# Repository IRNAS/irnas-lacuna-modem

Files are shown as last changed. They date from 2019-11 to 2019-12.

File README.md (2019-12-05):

# Irnas Lacuna modem
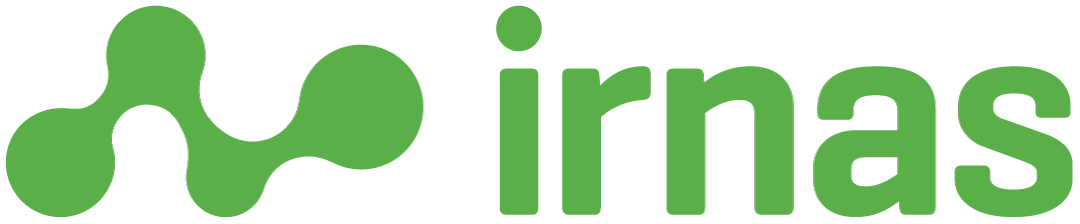
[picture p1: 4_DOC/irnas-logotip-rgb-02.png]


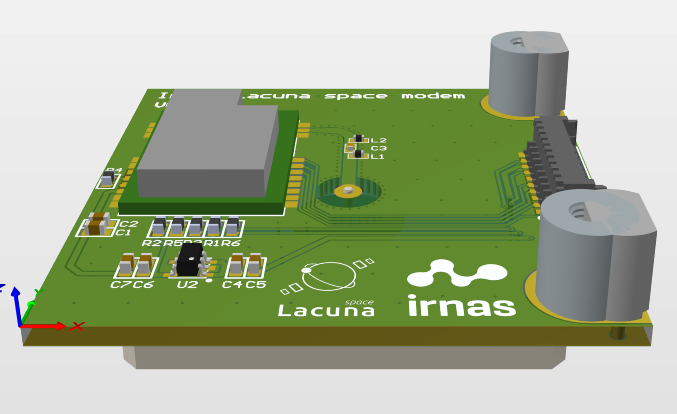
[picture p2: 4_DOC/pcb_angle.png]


## Folder structure
 - folder 1_SCHEMATIC includes Altium schematic files and PDF schematic
 - folder 2_PCB includes Altium PCB file, PDF PCB print and PDF 3D PCB print
 - folder 3_OUTPUT_FILES includes Gerber and NC Drill files, PDF Assembly file and Bill of Material
 - folder 4_DOC includes 3D step model of PCB and photos of device
 - folder 5_ALTIUM_FILES incudes all Altium Designer files (Libraries, Output job, Project document, ...)

## Specification
Device consists of:
 - Top side:
   - LoRa module - E22-900M22S
   - Fixed LDO Voltage Regulator 3.3 V - MIC5504-3.3YM5-TR
   - 10 pin PicoBlade connector
 - Bottom side:
   - Patch antenna 868 MHz - ISMP.868.35.6.A.02

Dimensions:  
 - Lenght: 45 mm
 - Height: 45 mm
 - PCB thickness: 1.6 mm

Mounting pins:  
 - Vertical pin (https://www.we-online.com/catalog/en/WP-SMBU_BLIND-HOLE/)
 - Angled pin (https://www.we-online.com/catalog/en/2ND_TAXONOMY$WP-SMRA_PINS/)

Connector:  
 Pin 1 - NC  
 Pin 2 - SPI_MOSI  
 Pin 3 - SPI_MISO  
 Pin 4 - SPI_SCK  
 Pin 5 - SPI_NSS  
 Pin 6 - NC  
 Pin 7 - DIO1  
 Pin 8 - 5V  
 Pin 9 - GPIO1  
 Pin 10 - GND  

## Features:
 - LoRa communication module with micro RF connector and patch antenna
 - Voltage regulator to 3.3 V

## License

All our projects are as usefully open-source as possible.

Hardware including documentation is licensed under [CERN OHL v.1.2. license](http://www.ohwr.org/licenses/cern-ohl/v1.2)

Firmware and software originating from the project is licensed under [GNU GENERAL PUBLIC LICENSE v3](http://www.gnu.org/licenses/gpl-3.0.en.html).

Open data generated by our projects is licensed under [CC0](https://creativecommons.org/publicdomain/zero/1.0/legalcode).

All our websites and additional documentation are licensed under [Creative Commons Attribution-ShareAlike 4 .0 Unported License](https://creativecommons.org/licenses/by-sa/4.0/legalcode).

What this means is that you can use hardware, firmware, software and documentation without paying a royalty and knowing that you'll be able to use your version forever. You are also free to make changes but if you share these changes then you have to do so on the same conditions that you enjoy.

Koruza, GoodEnoughCNC and IRNAS are all names and marks of Institut IRNAS Race. 
You may use these names and terms only to attribute the appropriate entity as required by the Open Licences referred to above. You may not use them in any other way and in particular you may not use them to imply endorsement or authorization of any hardware that you design, make or sell.

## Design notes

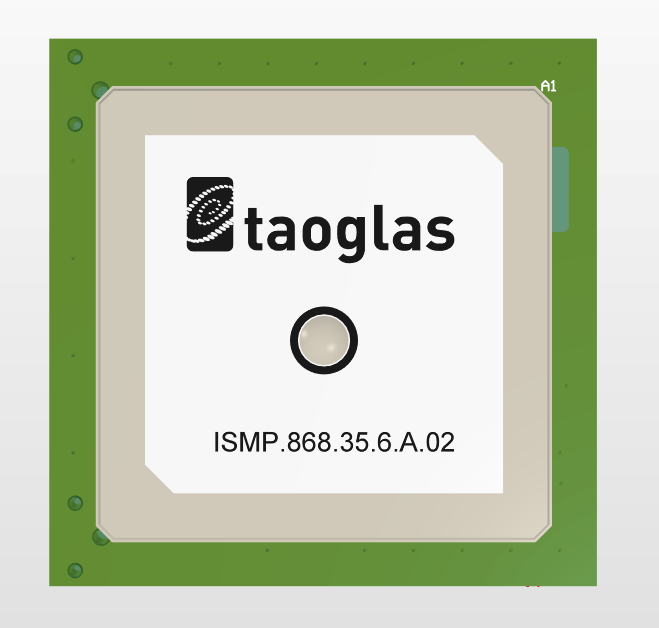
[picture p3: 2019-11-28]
4_DOC/pcb_bottom.png

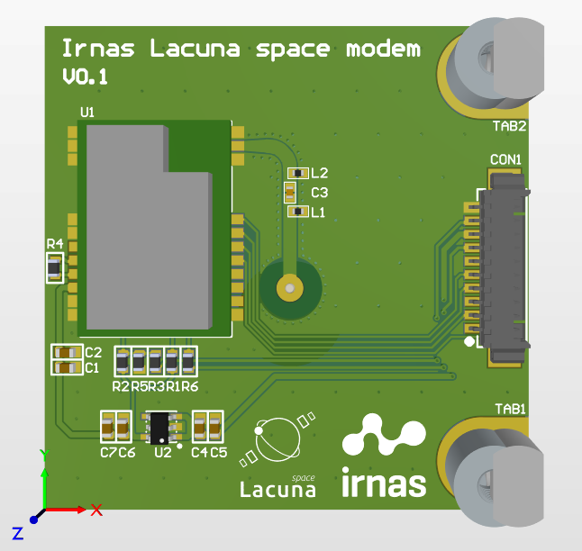
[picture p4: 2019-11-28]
4_DOC/pcb_top.png

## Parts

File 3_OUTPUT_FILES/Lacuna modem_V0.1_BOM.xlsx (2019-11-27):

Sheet: Part List Report
 | Component list |  |  | Lacuna modem
 | Source Data From: | Lacuna_modem.PrjPCB |  |  | Contact:
 | Project: | Lacuna_modem.PrjPCB
 | Variant: | None |  |  |  |  |  |  | IRNAS
 | Report Date: | 22. 11. 2019 | 10:42 |  |  |  |  |  | www.irnas.eu
 | Print Date: | 2019-11-22 | 10:42:34
# | Manufacturer Part Number | Manufacturer | Description | Footprint | Designator | Quantity | Supplier 1 | Supplier Part Number 1 | Supplier Order Qty 1 | Supplier Stock 1 | Supplier Unit Price 1 | Supplier Subtotal 1 | Supplier Currency 1
1 | C0402C189B5GACTU | KEMET | Multilayer Ceramic Capacitors MLCC - SMD/SMT 50volts 1.8pF C0G | CAP0402 | C3 | 1 | Farnell | 2820847
2 | GRM188R61H105KAALD | MURATA | MURATA - GRM188R61H105KAALD - CAP, MLCC, X5R, 1UF, 50V, 0603 | CAP0603 | C1, C4, C7 | 3 | Farnell | 1845736
3 | GRM188R71C104KA01J | MURATA | MURATA - GRM188R71C104KA01J - CAP, MLCC, X7R, 0.1UF, 16V, 0603 | CAP0603 | C2, C5, C6 | 3 | Farnell | 2688519
4 |  |  |  | E22-900M22S | U1 | 1
5 | LQG15HN4N3S02D | Murata | Inductor RF Chip Multi-Layer 4.3nH 0.3nH 100MHz 8Q-Factor Air 300mA 210mOhm DCR 0402 Paper T/R | IND0402 | L1, L2 | 2 | Digi-Key | 490-6563-1-ND
6 | SR42I010-R | Antenova | Patch Antenna, 868MHz, 2.17dBi Gain, 50ohm, Right Hand Circular Polarisation, Adhesive/Pin | ISMP.868.35.6.A.02 | A1 | 1 | Farnell | 2949079
7 |  |  | Wire-To-Board Connector, Right Angle, 1.25 mm, 10 Contacts, Header, PicoBlade 53261 Series | PICOBLADE 10PIN | CON1 | 1 | Farnell | 1125377
8 | CR0603-J/-000ELF | BOURNS | BOURNS - CR0603-J/-000ELF - RES, THICK FILM, 0R, 5%, 0.1W, 0603 | RES0603 | R3, R4, R6 | 3 | Farnell | 2008343
9 | MCMR06X103 JTL | MULTICOMP | MULTICOMP - MCMR06X103 JTL - RES, CERAMIC, 10K, 5%, 0.1W, 0603 | RES0603 | R1, R2, R5 | 3 | Farnell | 2073356
10 | LM2596DSADJG | ON SEMICONDUCTOR | Fixed LDO Voltage Regulator, 2.5V to 5.5V, 160mV Dropout, 3.3Vout, 300mAout, SOT-23-5 | SOT23-5 | U2 | 1 | Farnell | 2510377
11 |  |  | WP-SMBU SMD Internal blind-hole thread w. Pins | WP-SMBU | TAB1, TAB2 | 2 | Farnell | 2405986
 |  |  |  |  |  | 21 |  |  | 0 |  |  | 0
Approved |  |  |  | Notes
 |  |  |  | pcs: |  | 20 |  | Total |  | 0 |  | <none>
 |  |  |  |  |  |  |  | Price for 1pcs |  | 0.00 |  | <none>

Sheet: Project Information
Project Full Path | D:\OneDrive\IRNAS-Common\_NEW-IRNAS-COMMON\Lacuna-modem\Electronics\Lacuna_modem.PrjPCB
Project Filename | Lacuna_modem.PrjPCB
Variant Name | None
Data-Source Filename | Lacuna_modem.PrjPCB
Data-Source Full Path | D:\OneDrive\IRNAS-Common\_NEW-IRNAS-COMMON\Lacuna-modem\Electronics\Lacuna_modem.PrjPCB
Title | BOM for Project [Lacuna_modem.PrjPCB] (No PCB Document Selected)
Total Quantity | 21
Report Time | 10:42
Report Date | 22. 11. 2019
Report Date & Tine | 22. 11. 2019 10:42
Output Name | BOM
Output Type | BOM_PartType
Output Generator Name | BOM
Output Generator Description | Bill of Materials

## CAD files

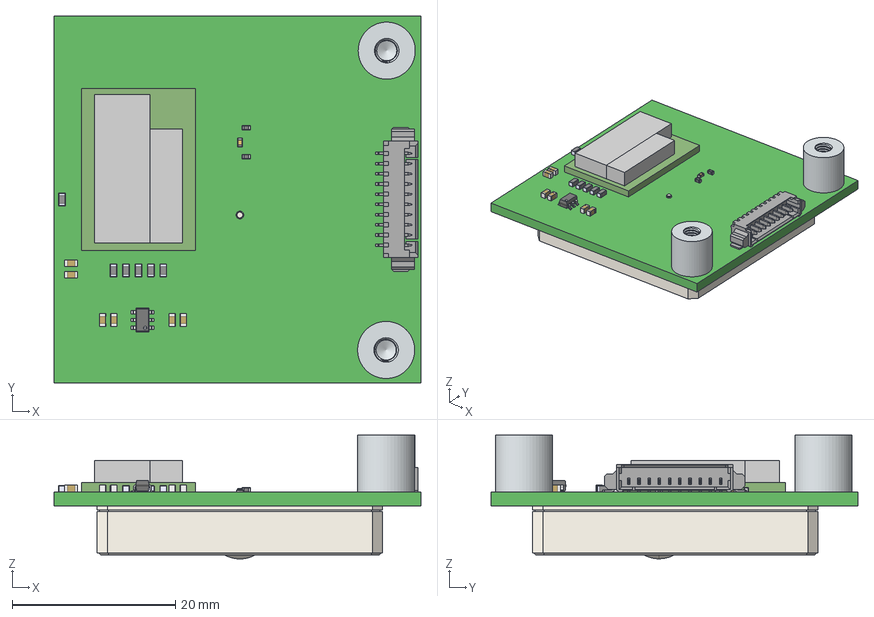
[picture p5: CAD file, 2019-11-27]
3_OUTPUT_FILES/Lacuna modem_V0.1_3D STEP.step
45.0 x 45.0 x 15.2 mm
7466103_(rev1) x 2
SOT23-6-2
Extruded x 3
R0603 x 6
Open_CASCADE_STEP_translator_6.8_1.1.1 x 2
Open_CASCADE_STEP_translator_6.8_1.1.2 x 2
Open_CASCADE_STEP_translator_6.8_1.2.1 x 2
Conn_Molex_53261-1071_eec_RGB6710886 x 56
C_SMD_0603 x 6
Open_CASCADE_STEP_translator_6.8_4.1.1
Open_CASCADE_STEP_translator_6.8_4.1.2
Open_CASCADE_STEP_translator_6.8_4.2.1
ISMP.868.35.6.A.02

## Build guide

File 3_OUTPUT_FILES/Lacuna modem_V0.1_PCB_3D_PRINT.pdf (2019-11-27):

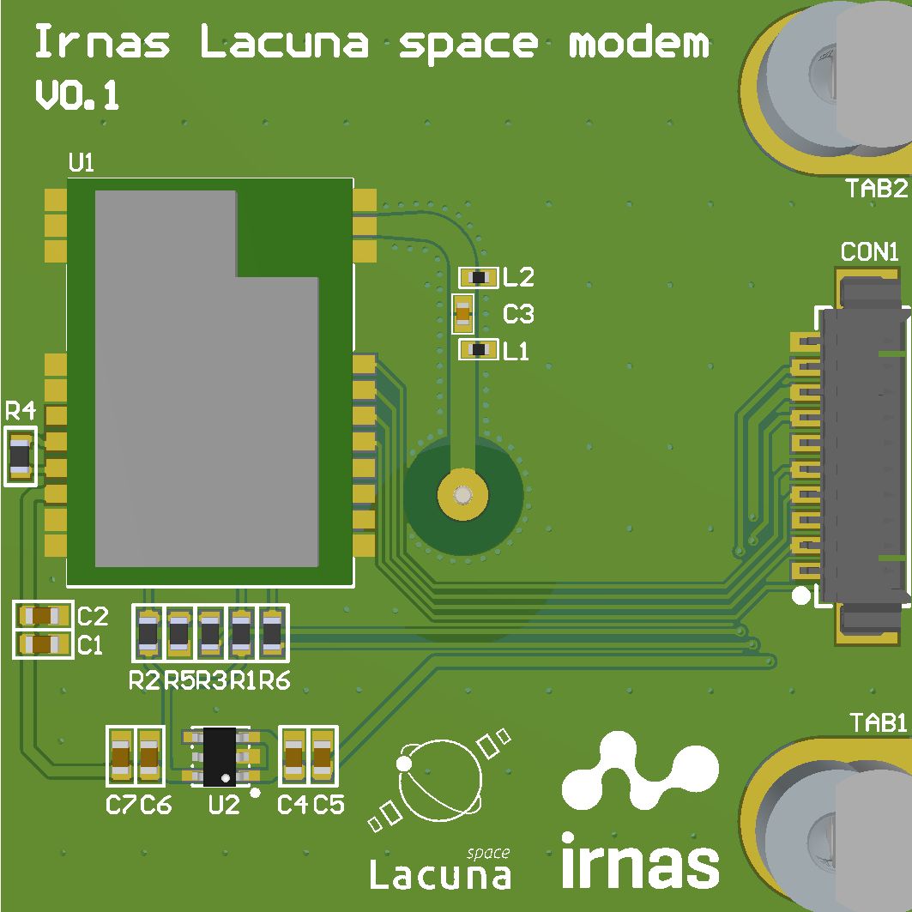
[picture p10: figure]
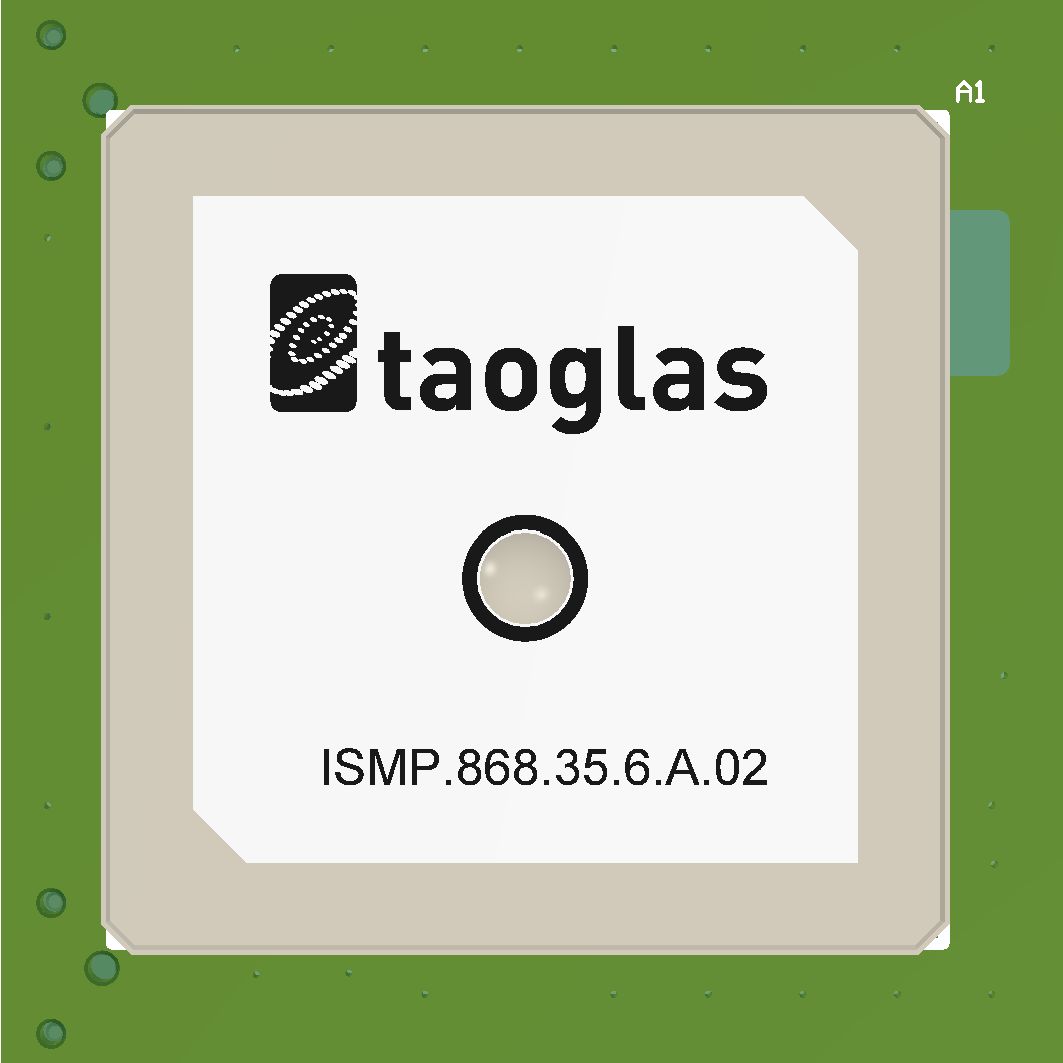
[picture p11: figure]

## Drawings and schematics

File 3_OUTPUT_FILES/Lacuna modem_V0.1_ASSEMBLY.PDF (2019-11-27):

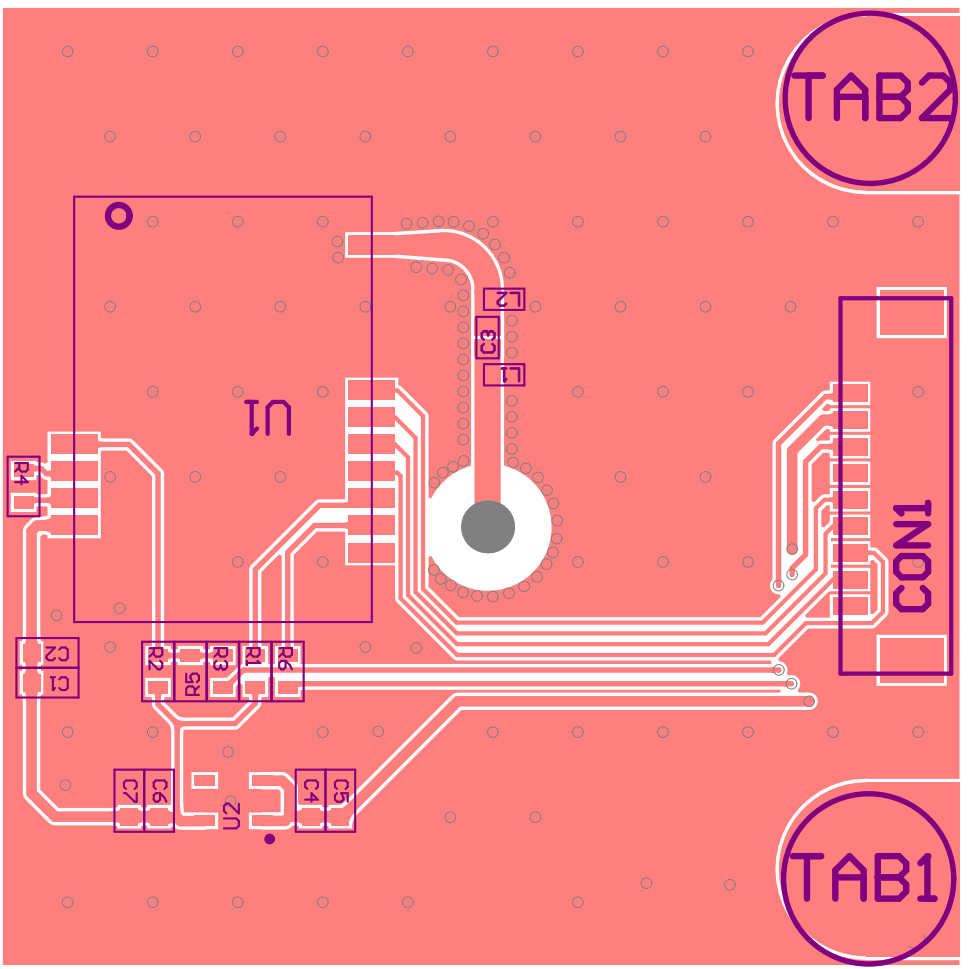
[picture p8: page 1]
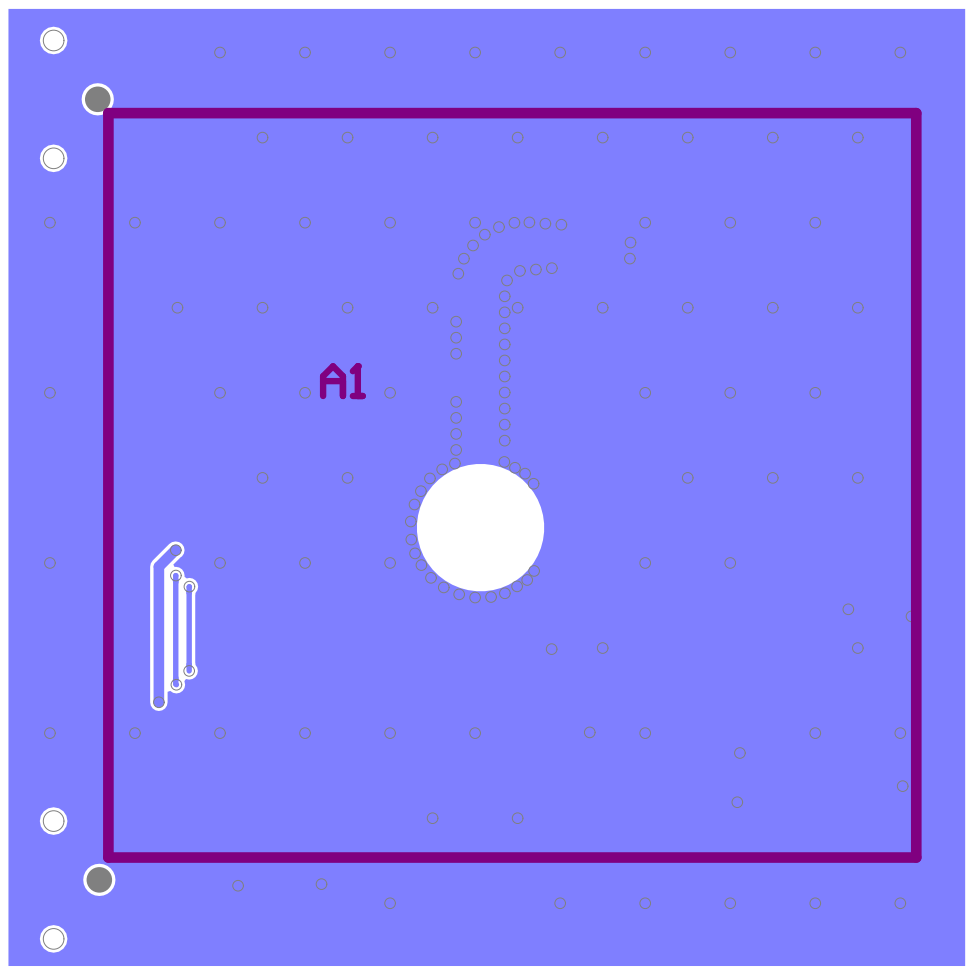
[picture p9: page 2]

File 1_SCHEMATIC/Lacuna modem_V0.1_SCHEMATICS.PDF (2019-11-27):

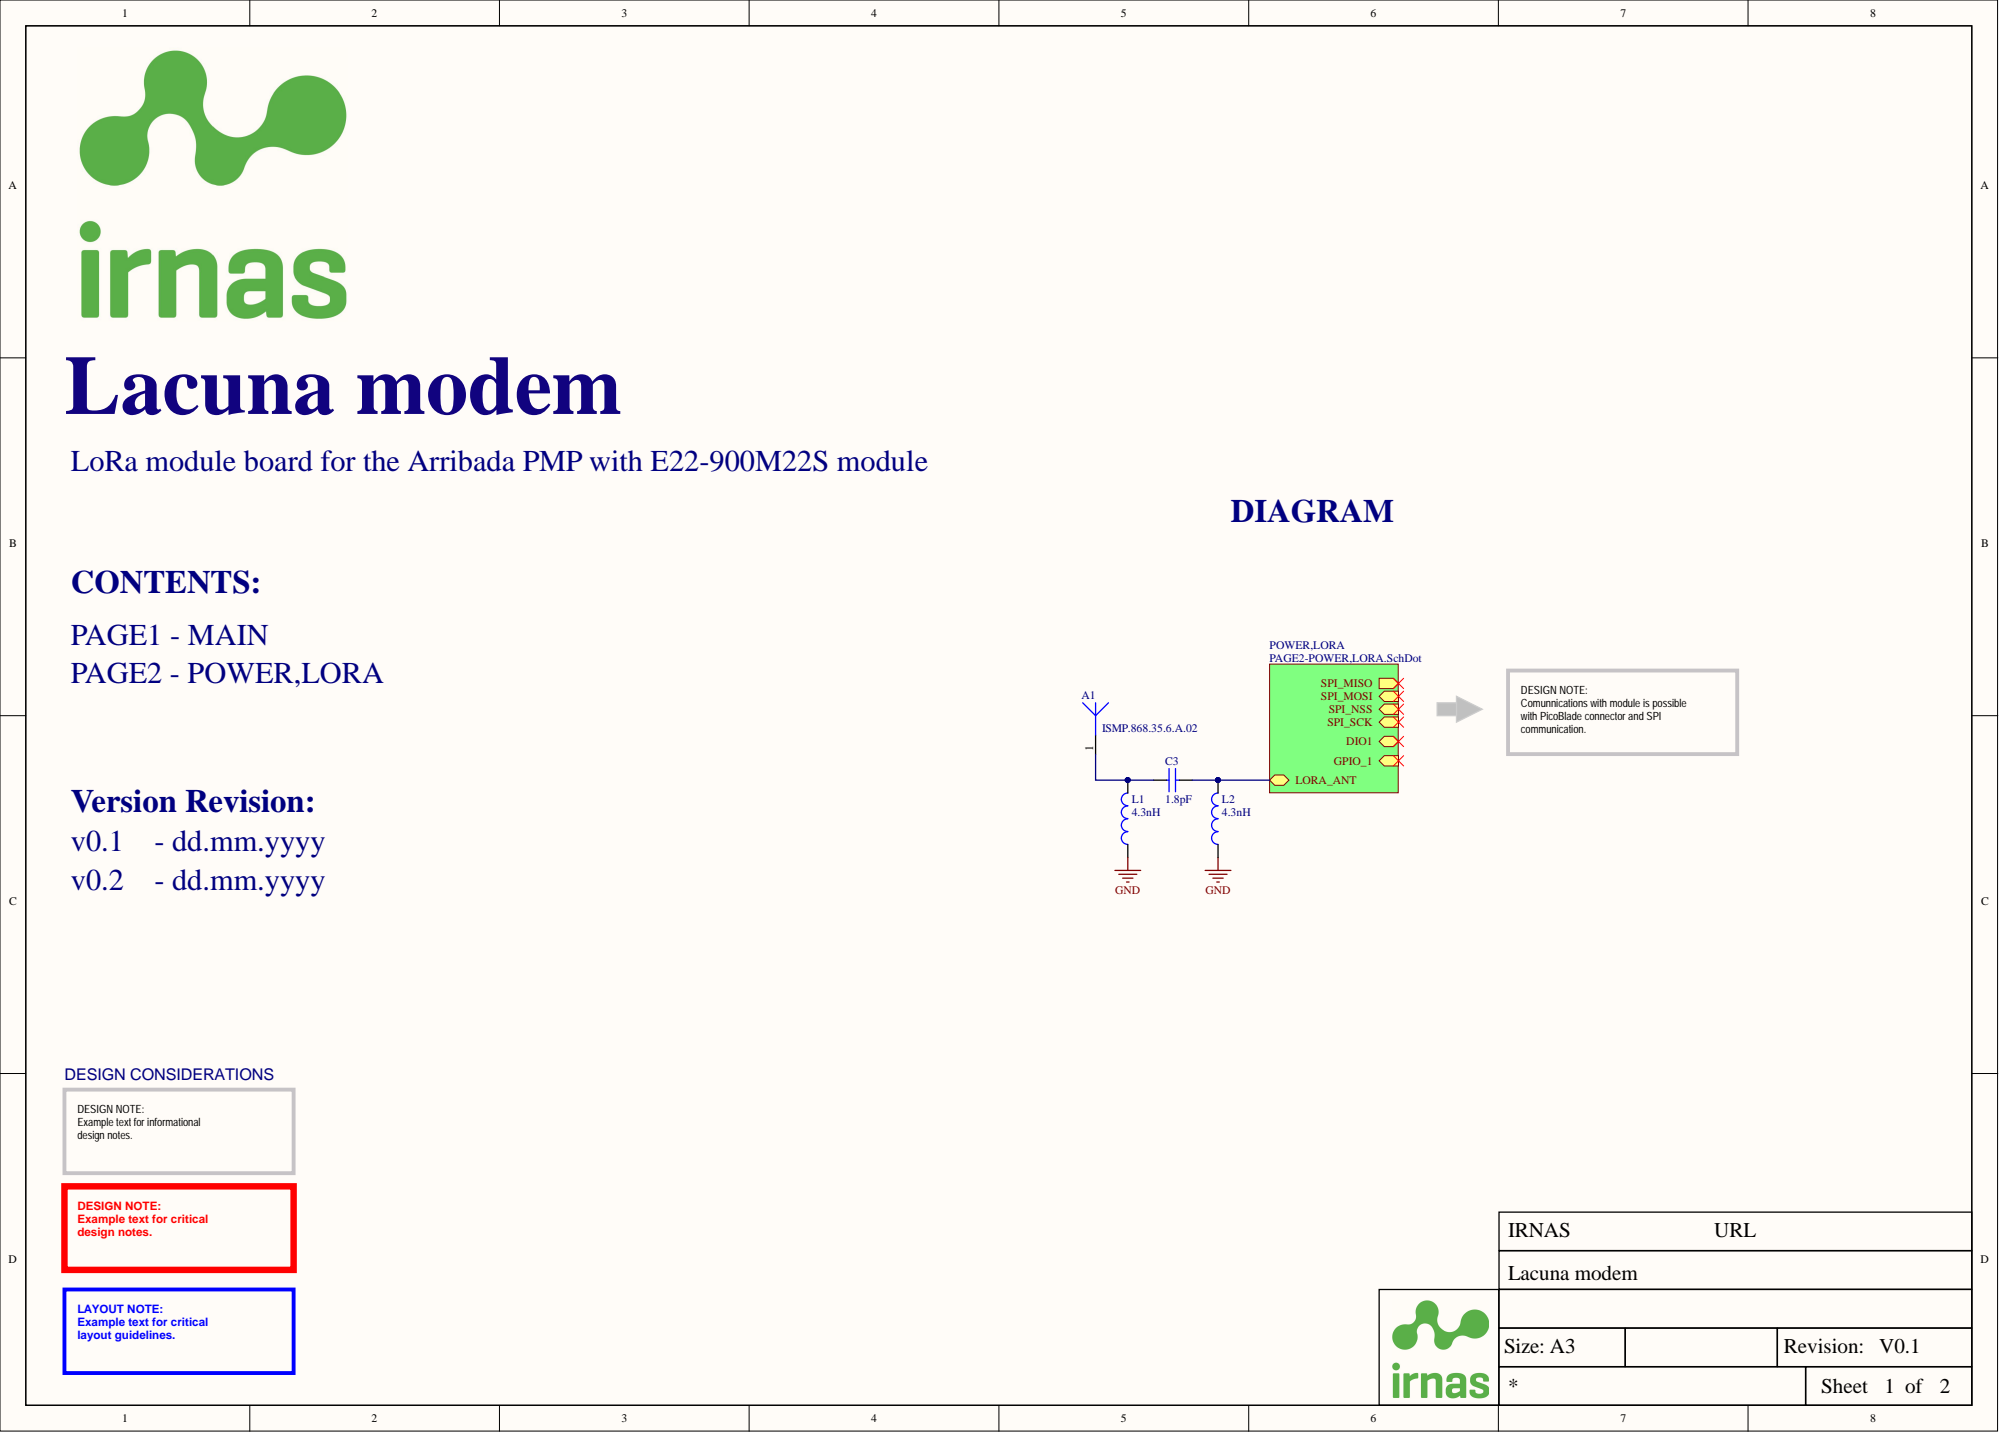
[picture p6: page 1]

LoRa module board for the Arribada PMP with E22-900M22S module

DESIGN NOTE:
Comunnications with module is possible
with PicoBlade connector and SPI
communication.

Example text for informational
design notes.

Example text for critical

LAYOUT NOTE:
layout guidelines.

Size: A3 | | Revision: V0.1

* | Sheet 1 of 2

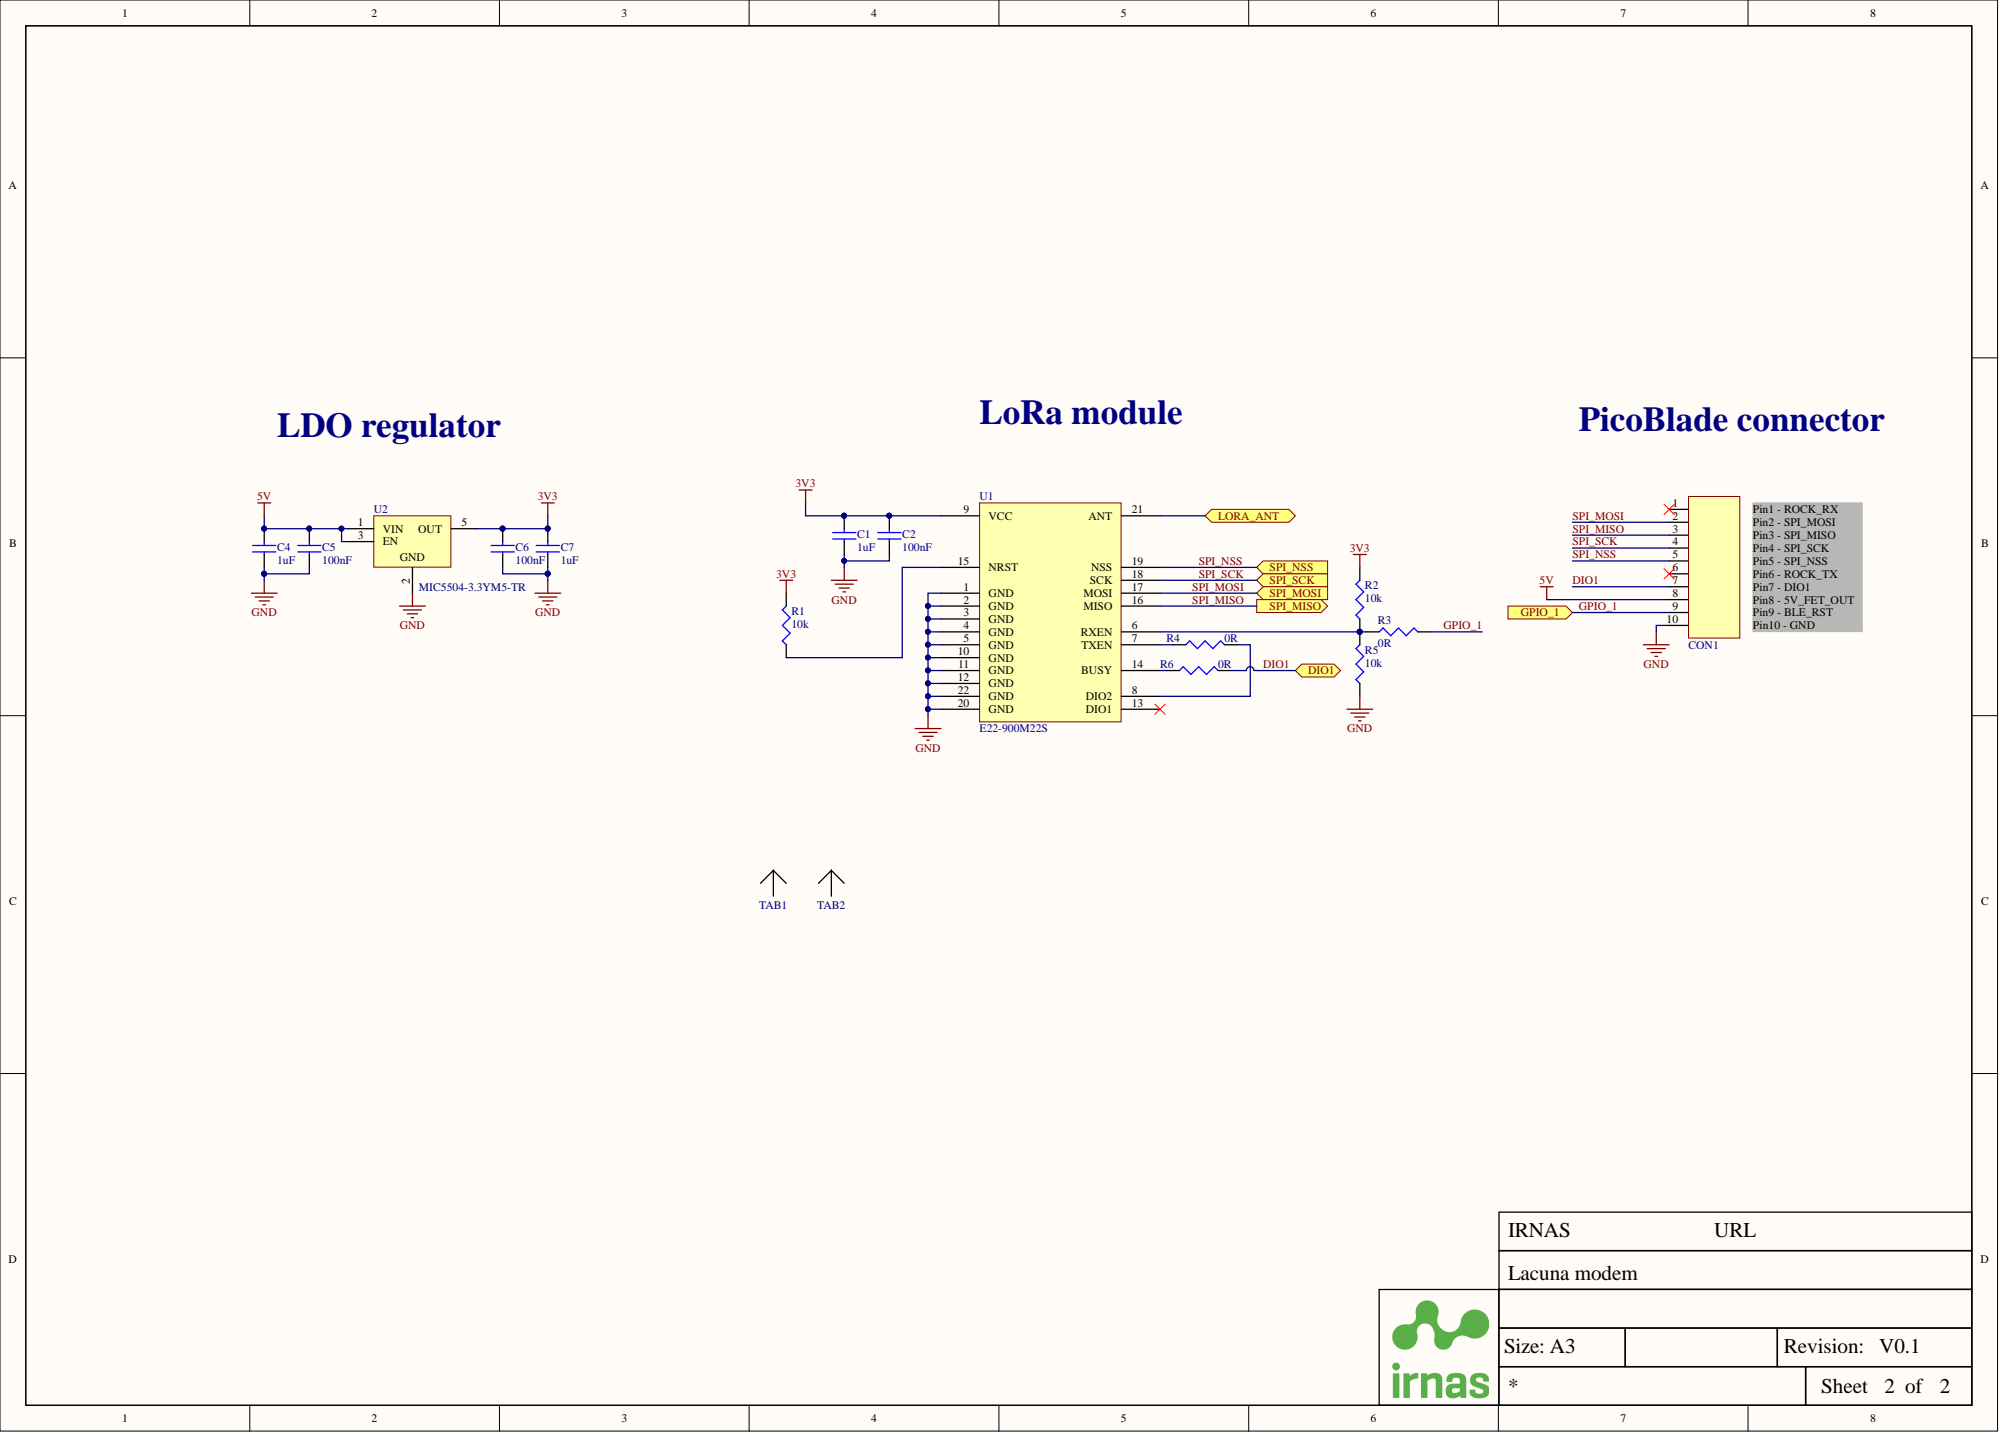
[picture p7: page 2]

Size: A3 | | Revision: V0.1

Sheet 2 of 2
